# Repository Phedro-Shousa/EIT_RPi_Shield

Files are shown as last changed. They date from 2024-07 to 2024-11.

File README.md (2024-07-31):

# EIT_RPi_Shield: Electrical Impedance Tomography (EIT) Shield for Structural Health Monitoring (SHM)

## Overview

This project is an Electrical Impedance Tomography (EIT) shield system designed for Structural Health Monitoring (SHM). This shield is an educational device that allows you to "plug-and-play" and actively collect data using a Raspberry Pi.

## Hardware Setup

The hardware setup consists of:
- 16 electrodes
- 1 High-Speed ADC
- Amplitude and Phase Detector
- 2 Multiplexers (Mux)
- Wave Generator

The shield is powered by the Raspberry Pi's 5V supply, with added protection. In addition to these sensors, this shield has extra free pinouts from the ADC analog inputs and the Raspberry Pi, allowing for the testing of other sensors and components.

## Project Status

This is the first stage of a work in progress, with the PCB design currently concluded. Future improvements and code will be developed in the future. This project belongs to the Würzburg University Luft- und Raumfahrtinformatik department.

**Note:** This shield is not recommended for medical use or for use on people, as it does not comply with current health regulations. It is intended only for SHM use on objects.

## Electrical Specifications

| Component | Specification |
|---|---|
| Power Supply | 5V (from Raspberry Pi) |
| Electrodes | - 16 Electrodes |
| | - 5 free ADC channels |
| ADC | - Input range ±5V or ±10V |
| | - 16-bit 20KSPS |
| Phase-Gain Detector | - Up to signals of 2.7GHz |
| | - Gain scale of 30mV/dB |
| | - Phase scale of 10mV/degree |
| Wave Generator | - Output signal up to 12MHz |
| | - Serial CLK up to 40MHz |
| | - Output signal voltage: Max 4.9V (load of 100Ω) or 4.5V (1kΩ) |
| | - Output signal voltage: Min 0.4V |
| MUX | - 4Ω on resistance |
| | - Rail-to-rail |
| | - Serial CLK up to 30MHz |

## Pictures
### Board

### Schematic
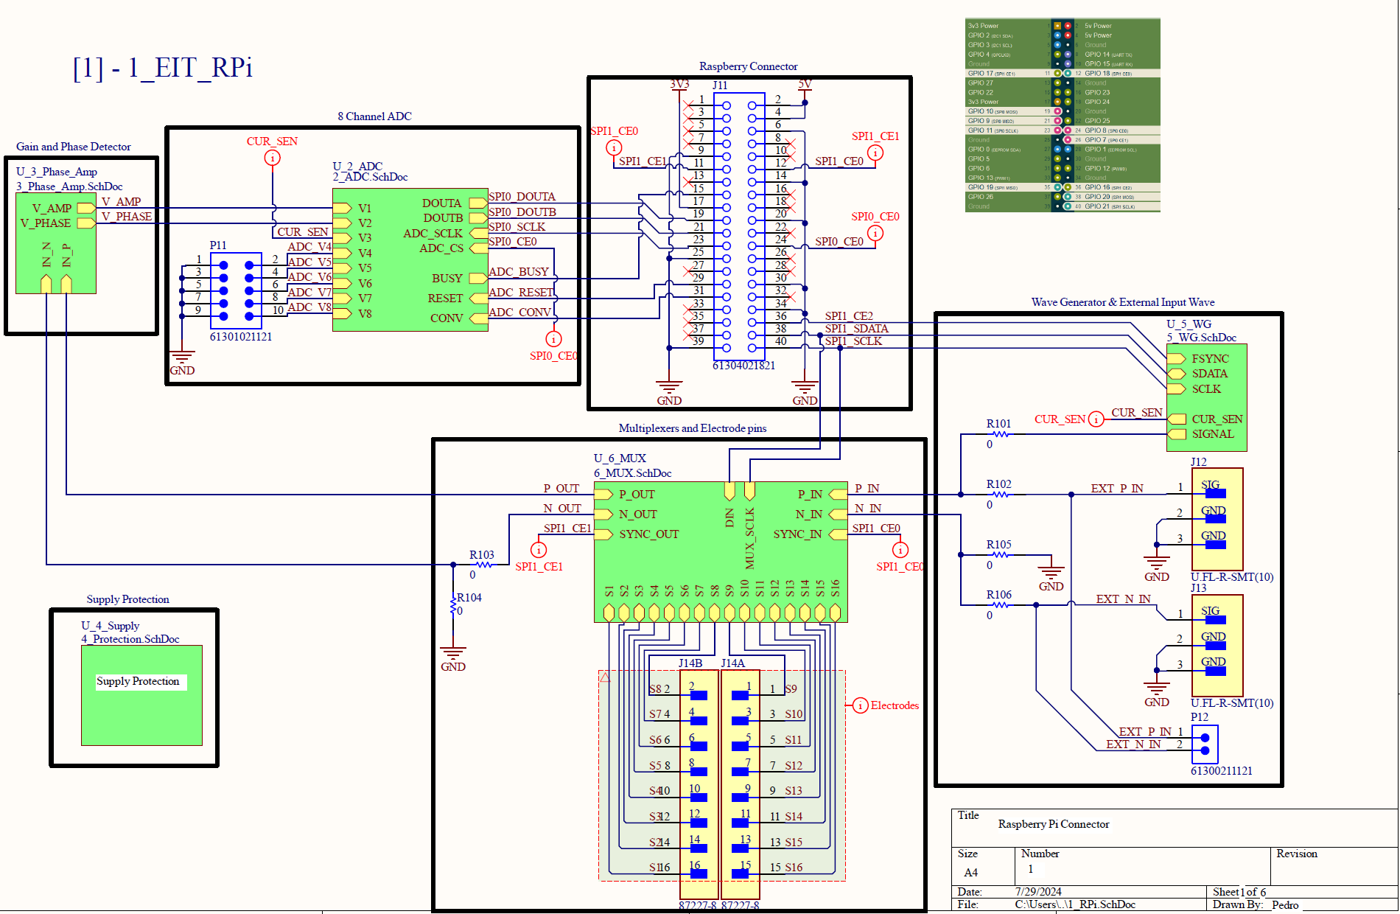
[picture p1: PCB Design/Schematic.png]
Schematic Picture


### PCB Layout
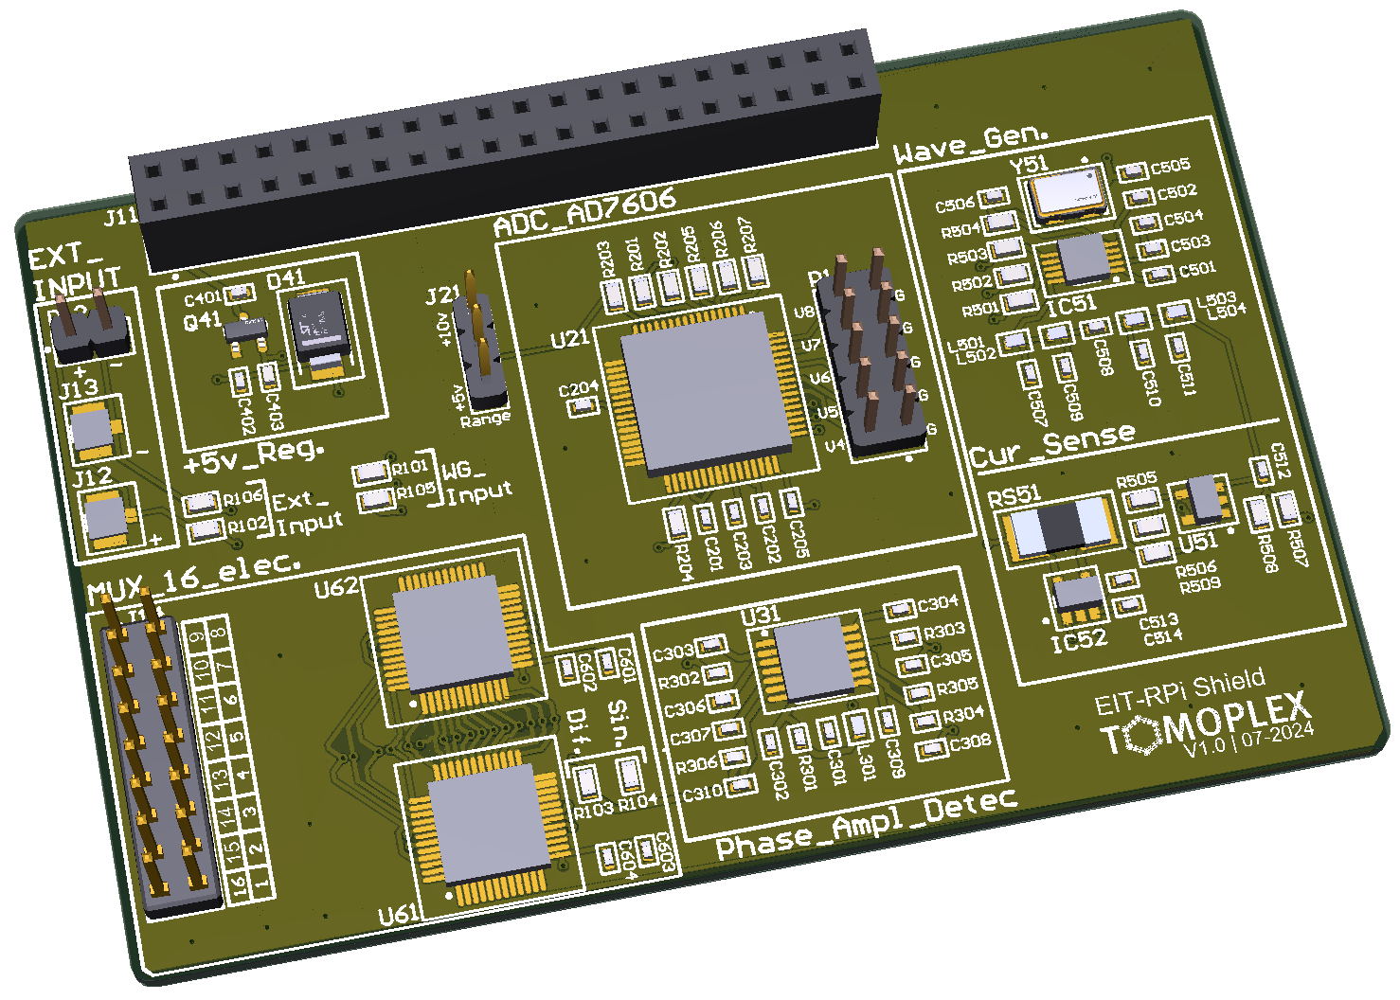
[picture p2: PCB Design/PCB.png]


---

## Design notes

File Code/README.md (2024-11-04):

# Code for EIT RPi Shield

This folder contains all the source code and scripts necessary to run the Electrical Impedance Tomography (EIT) Raspberry Pi Shield, which includes components like ADC interfacing, current sensing, multiplexing, and waveform generation.

### 1. `EIT_Test/`
This folder contains scripts for testing the entire EIT system.
- **AD7606.py**: Functions for interacting with the AD7606 ADC.
- **AD9833.py**: Code to control the AD9833 waveform generator.
- **ADG725.py**: Script for handling the ADG725 multiplexer.
- **main.py**: Main script to run EIT testing.
- **send_data.py**: Sends test data from the Raspberry Pi.
- **spi6-extended.dtbo**: SPI configuration for the test setup.

### 2. `ADC_AD7606/`
- **main.py**: Main script to run and initialize the ADC.
- **rpi_ad7606.py**: Supporting functions to handle the SPI communication between the Raspberry Pi and AD7606.

### 3. `Current_Sense/`
- **main.py**: Script to run current sensing using the MAX4376 current sense amplifier.
- **rpi_ad7606.py**: Functions for ADC (AD7606) interfacing.
- **spi6-extended.dtbo**: Device Tree Blob for configuring SPI6 interface.
- **spi6-extended.txt**: Configuration details for the SPI6.
- **Data_Results/**: Folder containing measurement results at different frequencies (1kHz to 1MHz).

### 4. `Mux/`
- **ADG725.py**: Script for initializing and using the multiplexer.
- **test.py**: Test script to verify multiplexer functionality.

### 5. `WavGen_AD9833/`
- **main.py**: Script for generating waveforms.
- **rpi_ad7606.py**: Helper functions to read waveform data using the AD7606.
- **spi6-extended.dtbo**: SPI6 interface configuration for waveform generation.

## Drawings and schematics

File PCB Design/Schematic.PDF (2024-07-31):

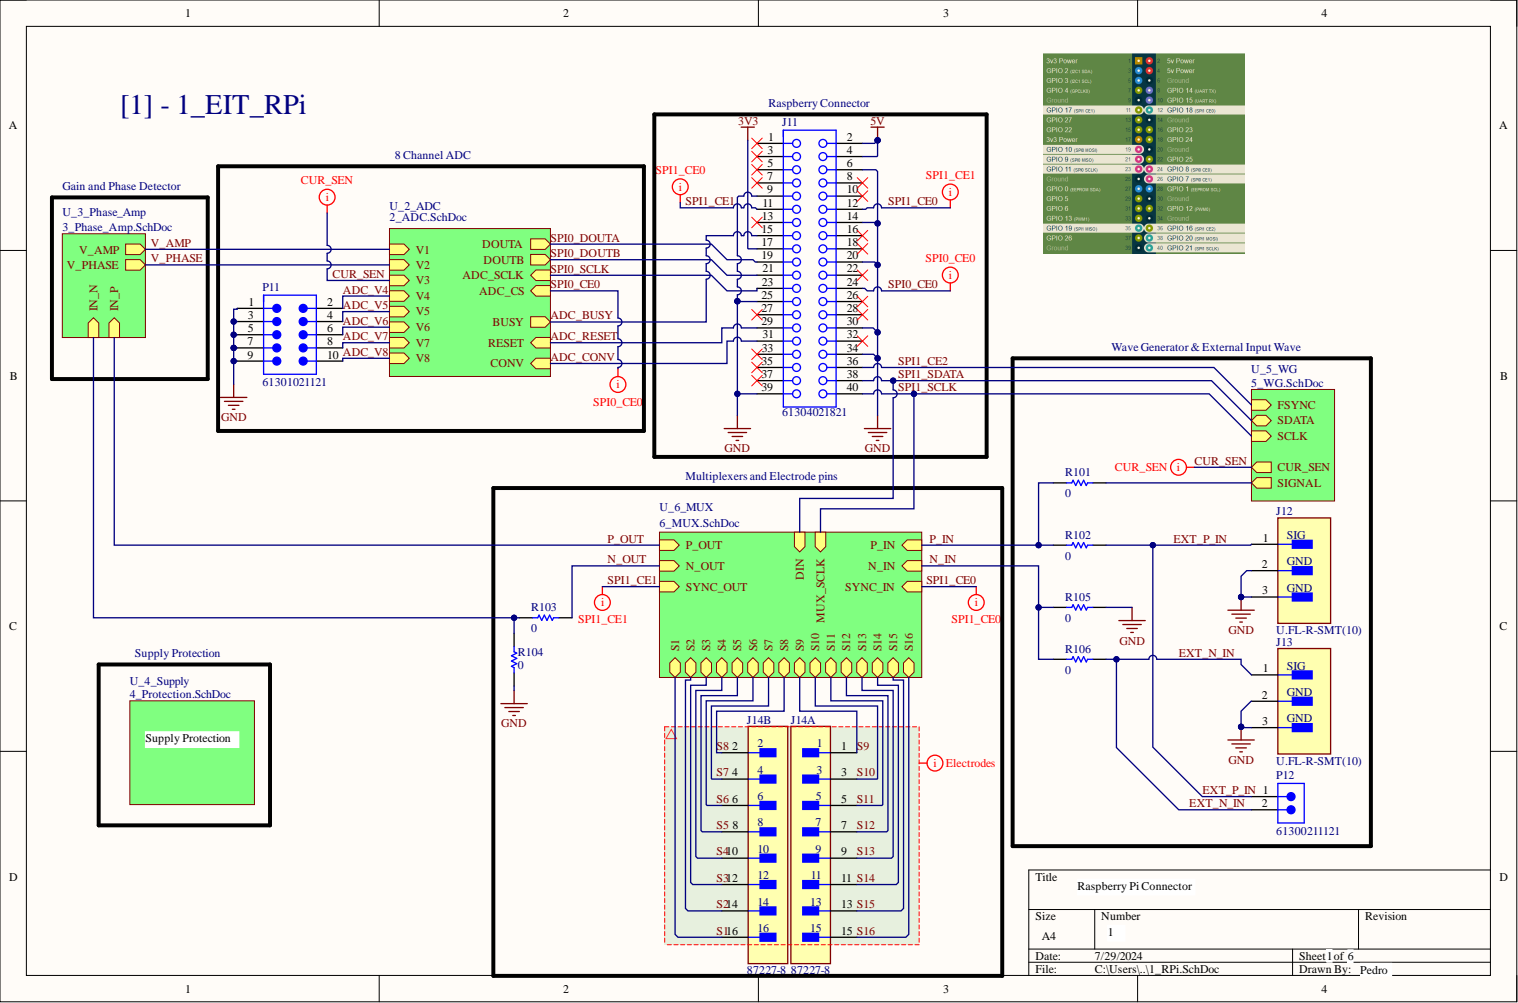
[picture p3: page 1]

Gain and Phase Detector

CUR_SEN | i

V_PHASE

ADC_V5 | | ADC_BUSY

ADC_V7 | ADC_RESET

V7 RESET V8 CONV

Wave Generator & External Input Wave

SPI0_CE0 | i | 37 | 38

Multiplexers and Electrode pins

P_OUT | U_6_MUX 6_MUX.SchDoc | P_IN N_IN

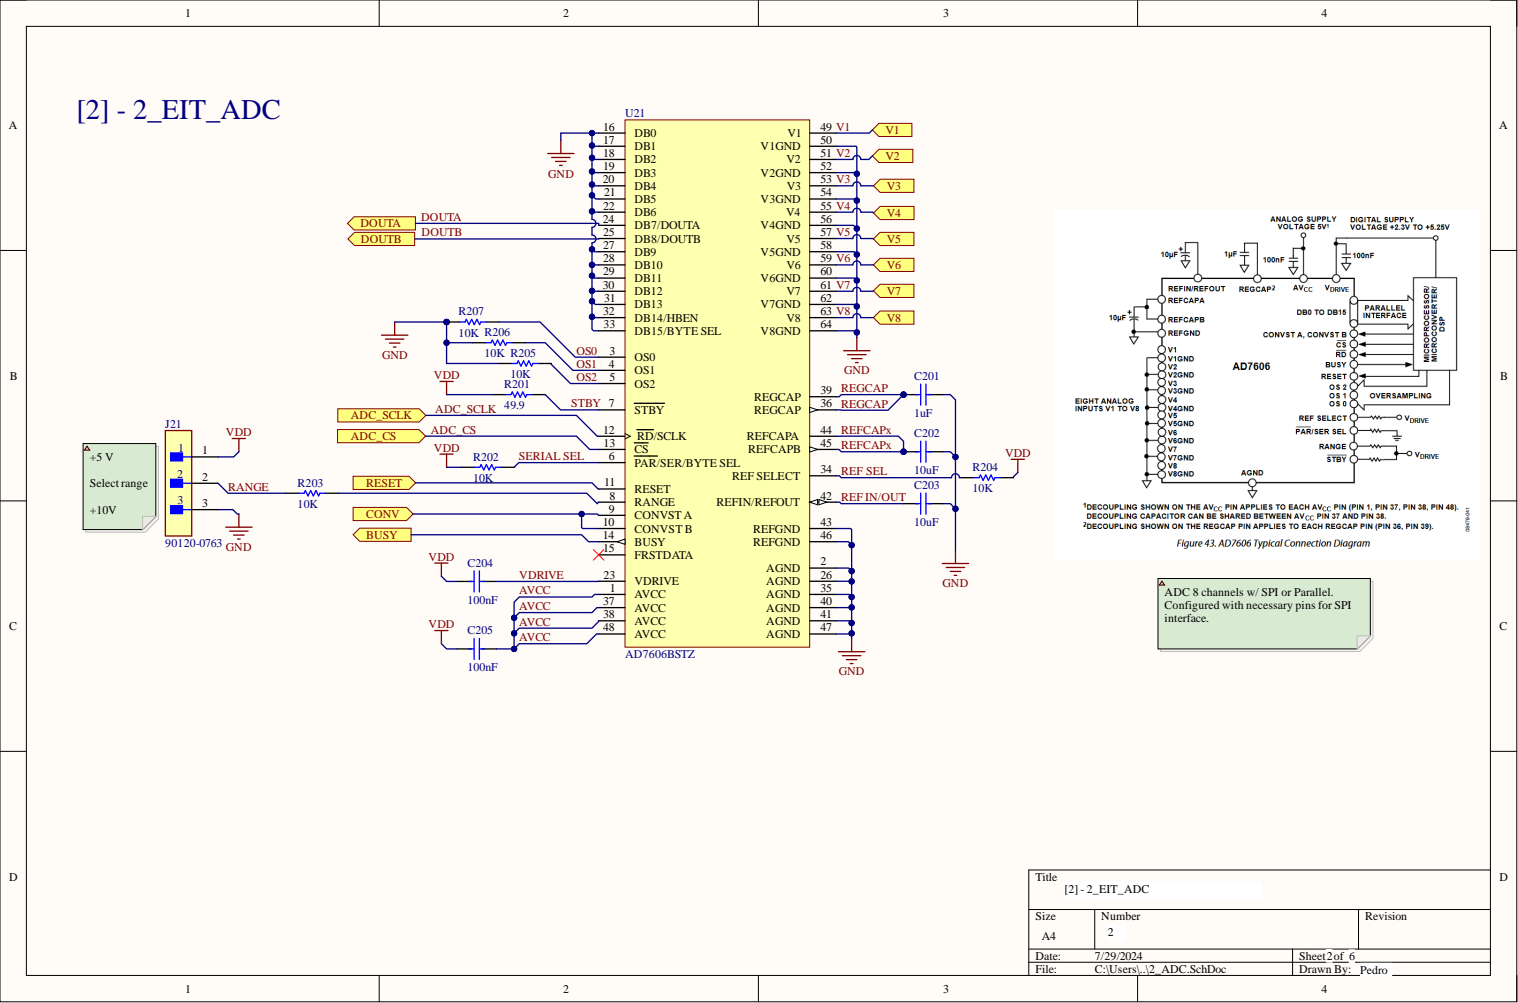
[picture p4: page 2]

RD/SCLK 12
PAR/SER/BYTE SEL 6

ADC 8 channels w/ SPI or Parallel.
Configured with necessary pins for SPI
interface.

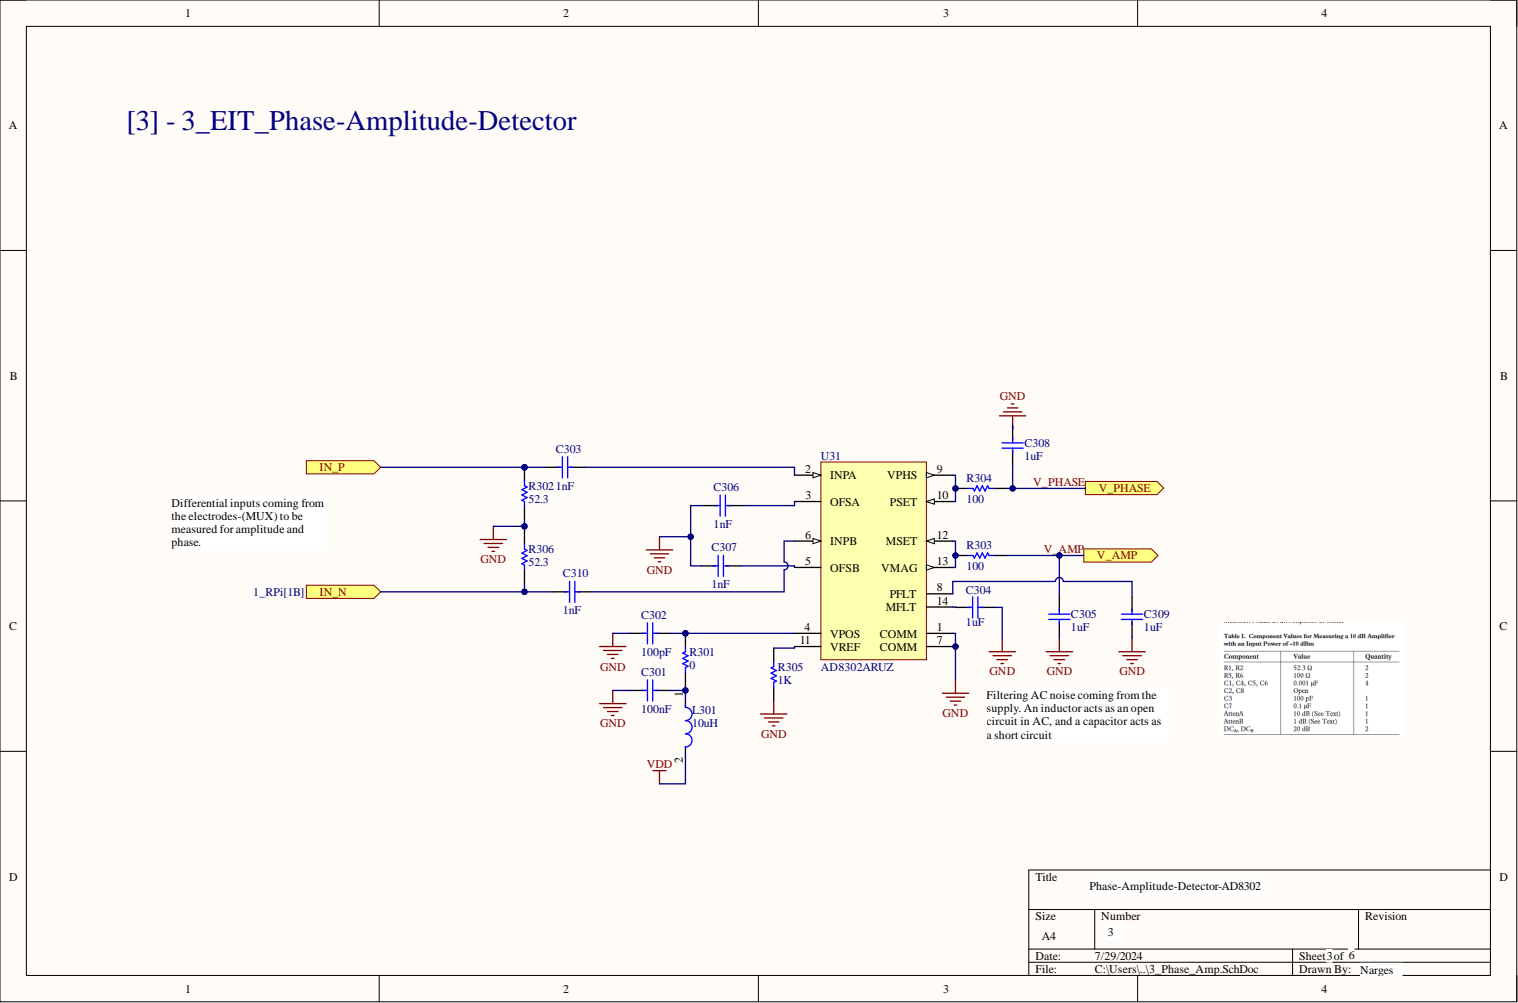
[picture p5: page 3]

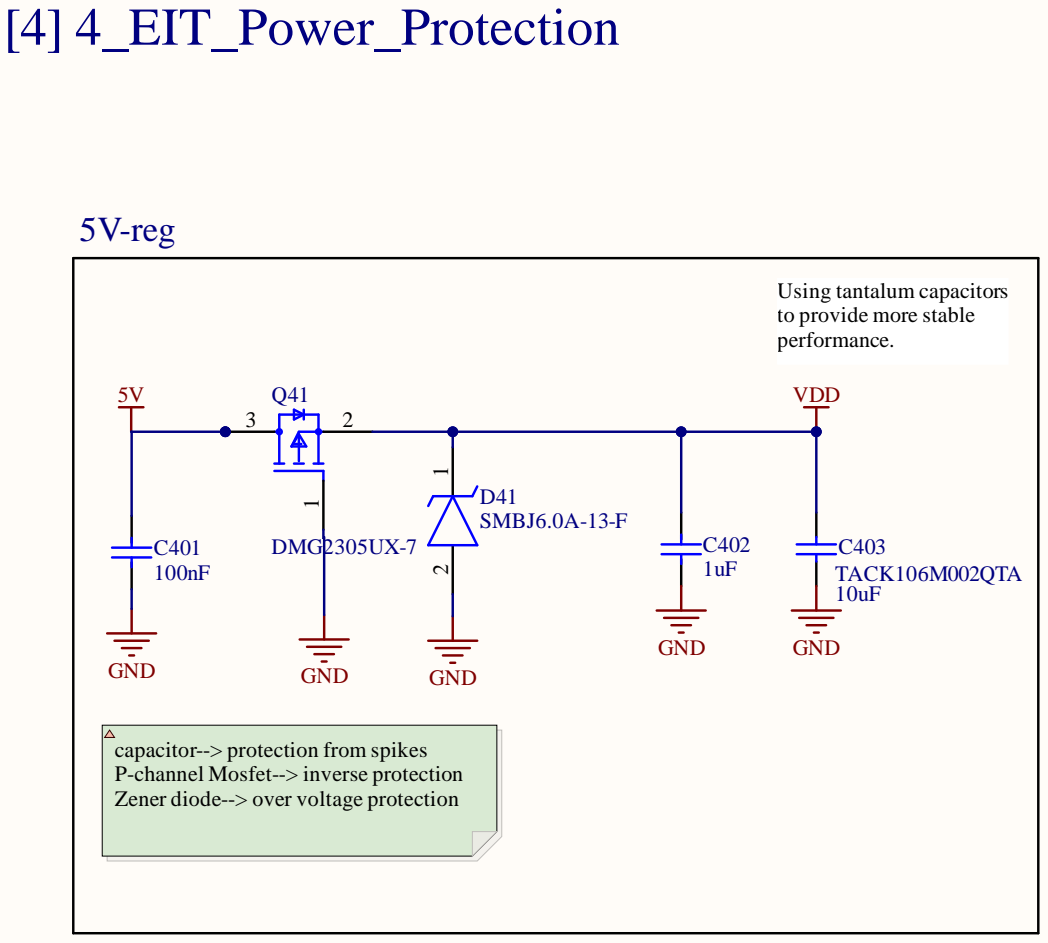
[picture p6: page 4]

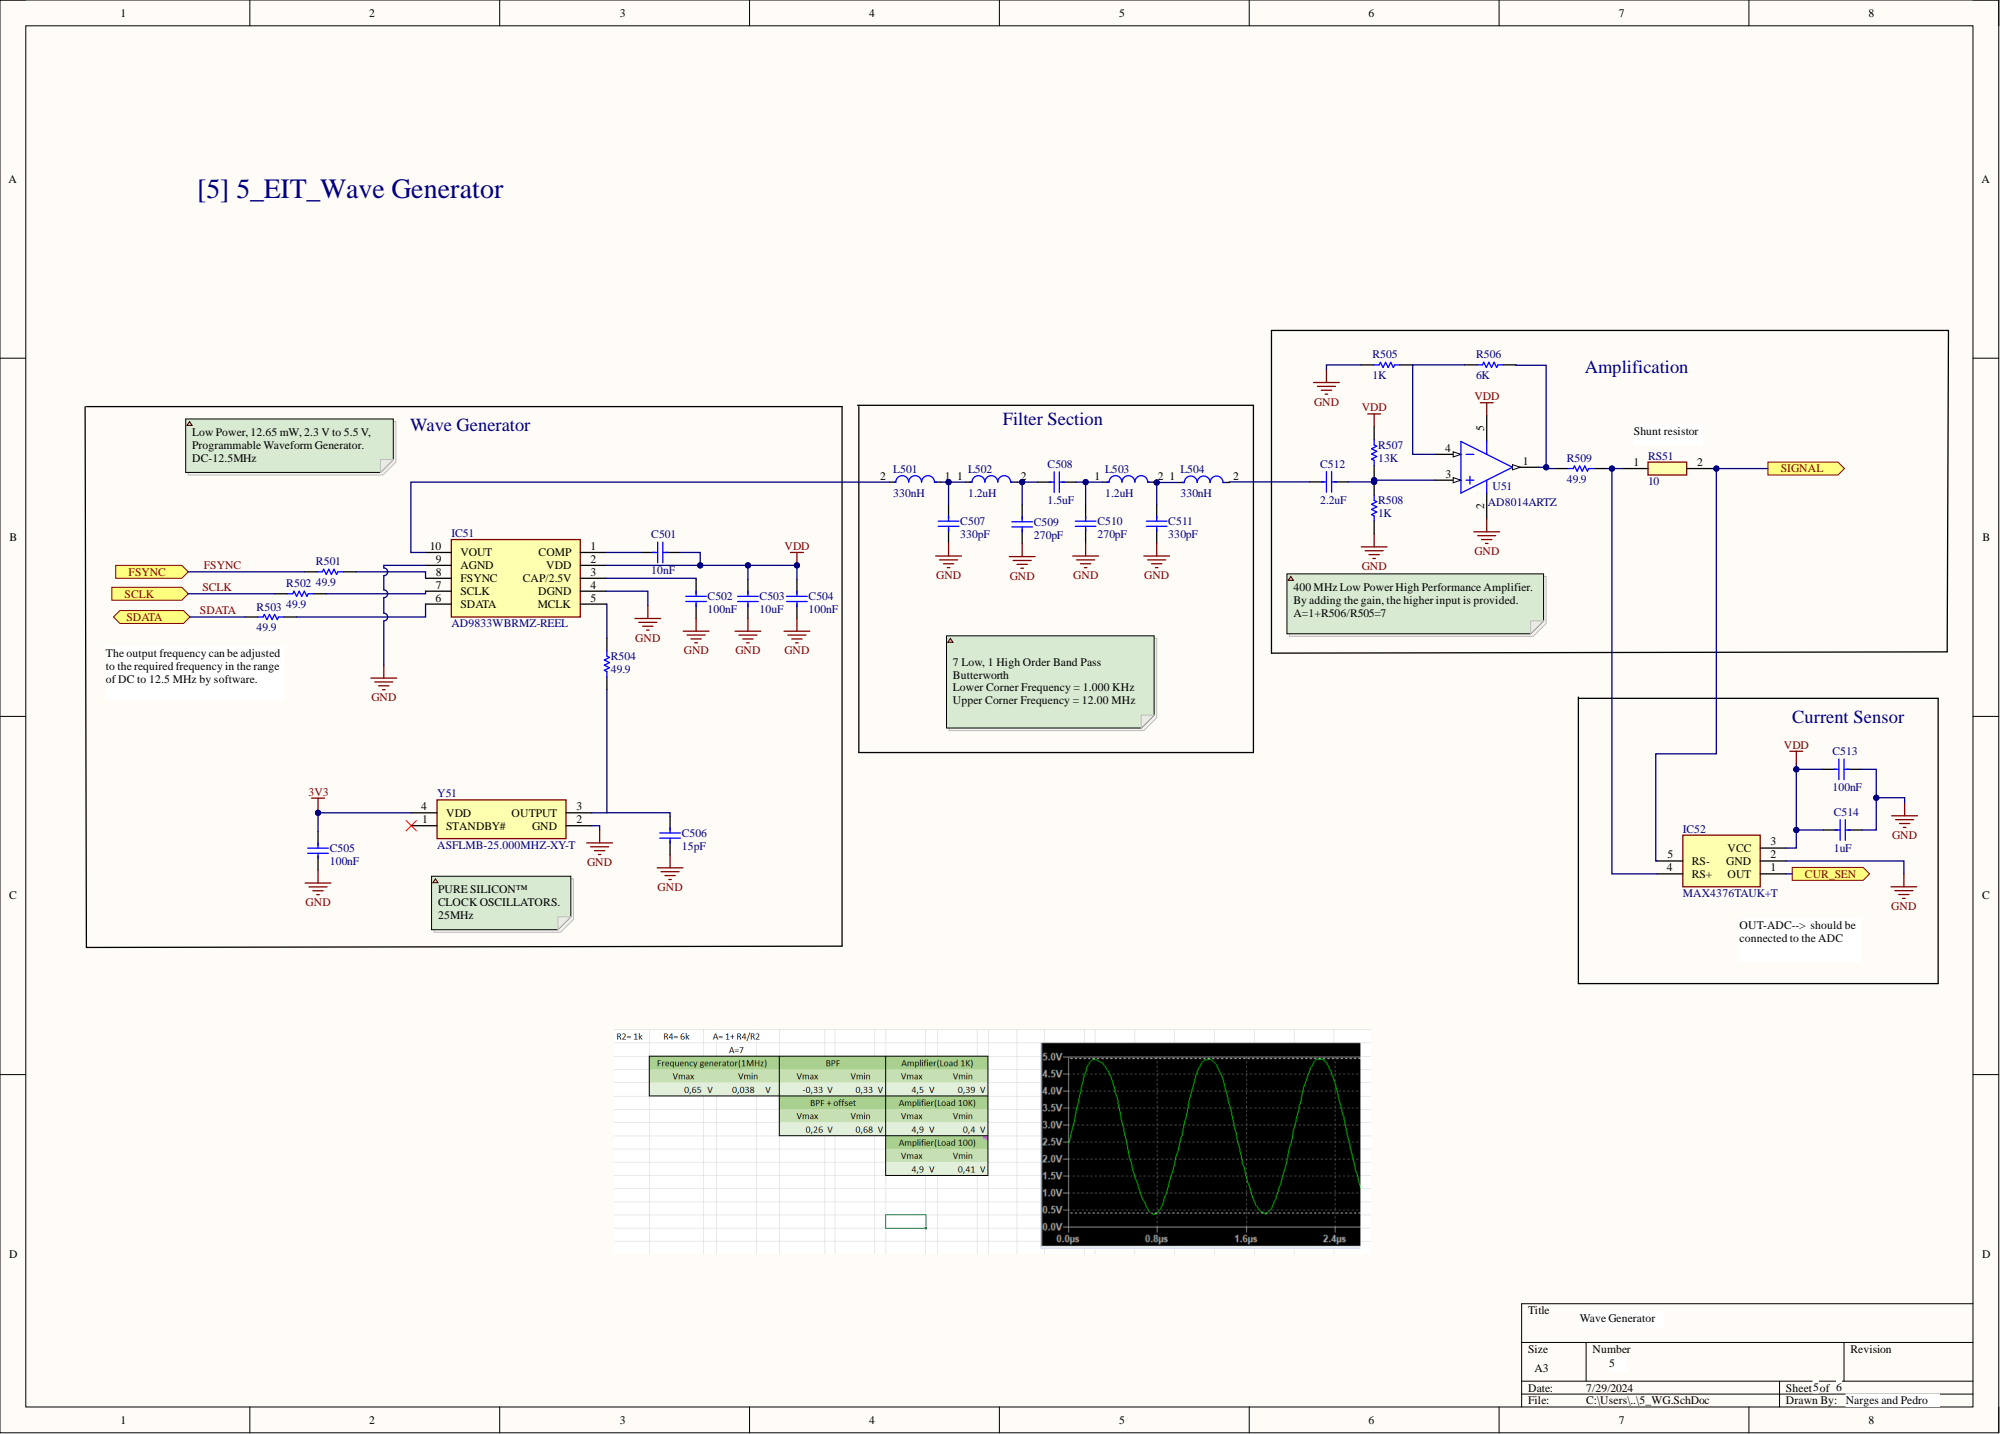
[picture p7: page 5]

Low Power, 12.65 mW, 2.3 V to 5.5 V,
Programmable Waveform Generator.
DC-12.5MHz

400 MHz Low Power High Performance Amplifier.
By adding the gain, the higher input is provided.

The output frequency can be adjusted
to the required frequency in the range
of DC to 12.5 MHz by software.

7 Low, 1 High Order Band Pass
Butterworth
Lower Corner Frequency = 1.000 KHz
Upper Corner Frequency = 12.00 MHz

OUT-ADC--> should be
connected to the ADC

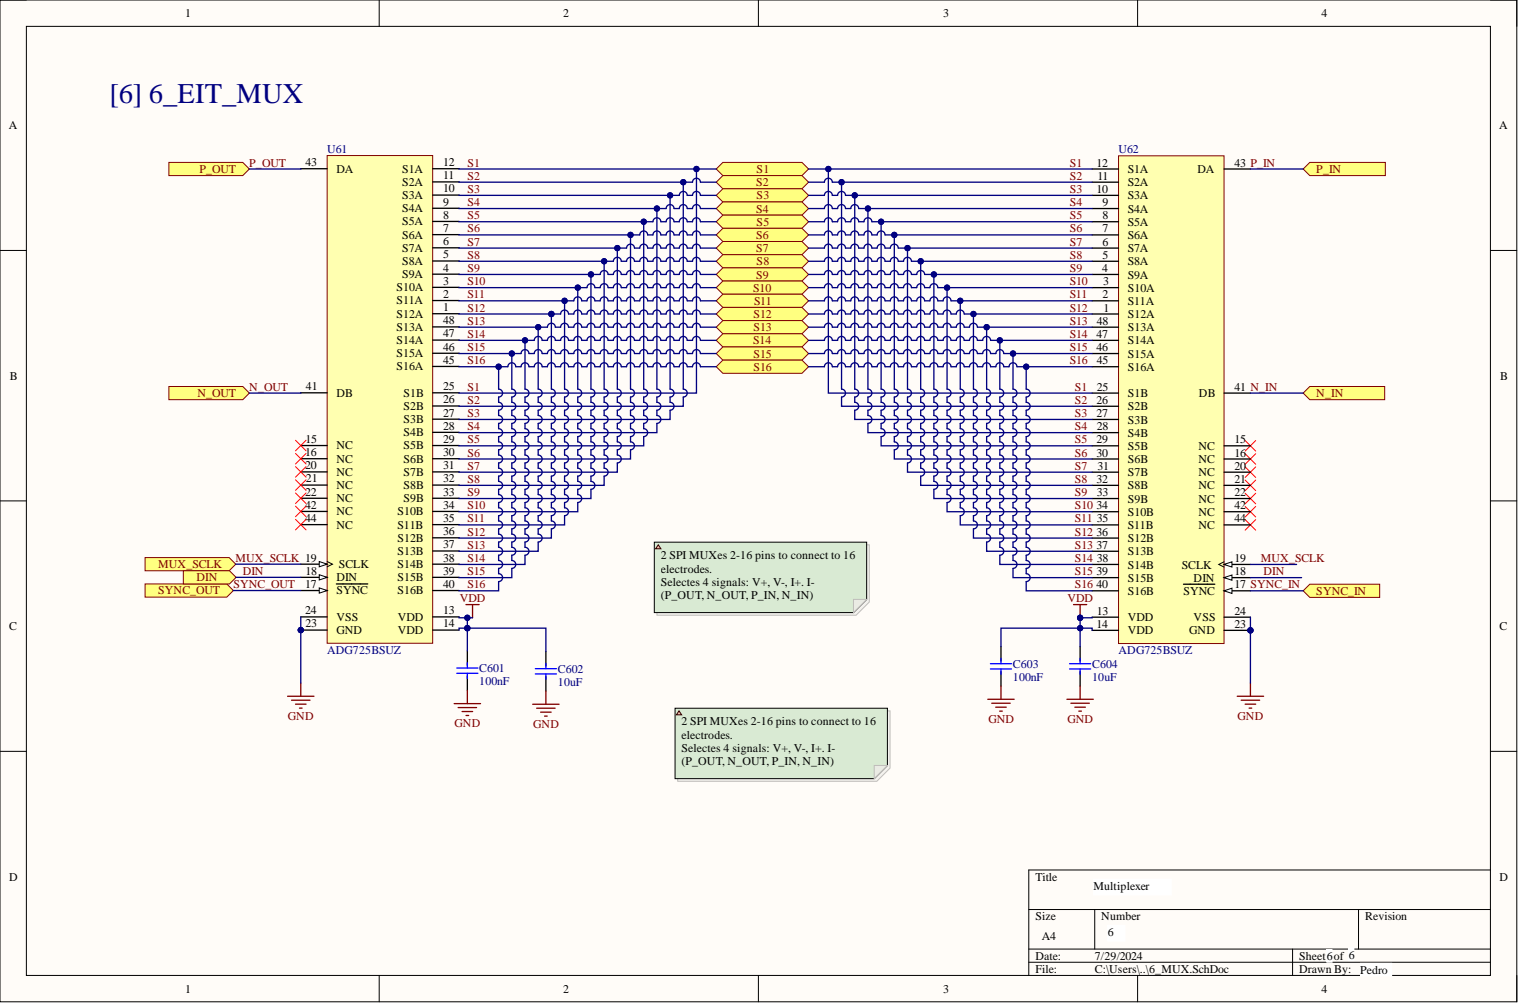
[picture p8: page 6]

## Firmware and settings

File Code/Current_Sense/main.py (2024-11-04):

import spidev
import RPi.GPIO as GPIO
import keyboard  # To detect keypresses
import rpi_ad7606 as adc
import time
import subprocess

def write_data_to_file(data, filename="/home/pedro/Desktop/log.txt"):
    # Write the data to a temporary file on Raspberry Pi
    with open(filename, 'w') as f:
        f.write(data)


def transfer_file_to_laptop(filename):
    # SSH details
    user = "Pedro Sousa"  # Replace with your laptop's username
    ip = "132.187.210.53"  # Replace with your laptop's IP address

    # Correct the file path on Windows laptop with double backslashes and quotes
    destination_path = r"C:\\Users\\Pedro Sousa\\Desktop\\TOMOPLEX\\Redesign\\Rasp_Code\\log.txt"

    # Use scp to transfer the file to the laptop
    command = f"scp {filename} \"{user}@{ip}:{destination_path}\""
    
    # Execute the scp command to transfer the file
    subprocess.run(command, shell=True)

def main():
    freq = 1000
    ClockFreq = 25000000
    
    print("Wav_Gem Test \n")
    GPIO.setmode(GPIO.BCM)
    spi = spidev.SpiDev(6, 2)
    spi.max_speed_hz = 10000000 
    spi.mode = 0b10
            
    adc_pins = {'standby':None, 'convsta':6, 'reset':5, 'busy':22, '1stData':None}
    adc1 = adc.AD7606_SPI(5, 'simultaneous', adc_pins)
    print("ADC Object Created \n")
    adc1.ADCreset()
    print("ADC Reset \n")
    
    # Send a reset
    spi.xfer([0x21, 0x00]) 
    print("Reset 0x2100 \n")
    
    # Calculate frequency word to send
    word = hex(int(round((freq * 2**28) / ClockFreq)))
    
    # Split frequency word onto its separate bytes
    MSB = (int(word, 16) & 0xFFFC000) >> 14
    LSB = int(word, 16) & 0x3FFF
    
    # Set control bits DB15 = 0 and DB14 = 1; for frequency register 0
    MSB |= 0x4000
    LSB |= 0x4000
    
    # Send LSB
    high, low = divmod(LSB, 0x100)
    spi.xfer([high, low])  # LSB
    
    # Send MSB
    high, low = divmod(MSB, 0x100)
    spi.xfer([high, low])  # MSB
    
    # Print the hexadecimal representation of MSB and LSB
    print(f"Frequency register MSB: {hex(MSB)}, LSB: {hex(LSB)}")
    
    # Phase register 0°
    spi.xfer([0xC0, 0x00])  # MSB
    print("Phase register 0xC000 \n")
    
    # Sine wave
    spi.xfer([0x00, 0x00])  # Sine
    print("Sine 0x0000 \n")
    
    channel = 3
    # Format the ADC readings as a string
    data = ""
    samples = 1024
    
    while samples > 0:
        r = adc1.ADCread(channel)
        reading = "{v}".format(v=r)
        data += reading + "\n"
        samples -= 1
    
    print(data)
    # Write the formatted data to a file on the Raspberry Pi
    write_data_to_file(data)        
    # Transfer the file to the Windows laptop
    transfer_file_to_laptop("/home/pedro/Desktop/log.txt")
    
    adc1.close()  # Close the SPI and cleanup GPIO

    
if __name__ == '__main__':
    main()

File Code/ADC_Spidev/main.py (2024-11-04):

import time
import rpi_ad7606 as adc

def main():
    adc_pins = {'standby':None, 'convsta':6, 'reset':5, 'busy':22, '1stData':None}
    adc1 = adc.AD7606_SPI(5, 'simultaneous', adc_pins)
    print("ADC Object Created \n")

    adc1.ADCreset()
    print("ADC Reset \n")
    
    r = adc1.ADCread()
    _ch = 1
    for _r in r:
        print(f"Channel {_ch}: {_r} volts. \n")
        _ch += 1
        time.sleep(1)

    adc1.ADCreset()
    print("ADC Reset \n")

    adc1.close()  # Close the SPI and cleanup GPIO

if __name__ == '__main__':
    main()

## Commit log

2024-07-25 add _PCB Design_ folder
    [1_RPi.SchDoc, 2_ADC.SchDoc, 2_RPi.PcbDoc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]
2024-07-25 title size update
    [2_ADC.SchDoc]
2024-07-25 Generating Documentation
    [2_RPi.PcbDoc, PCB_Project.PrjPcb]
2024-07-25 update output doc
    [2_RPi.PcbDoc]
2024-07-25 fix folder name
    [1_RPi.SchDoc, 2_ADC.SchDoc, 2_RPi.PcbDoc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]
2024-07-29 updating info text
    [3_Phase_Amp.SchDoc, 4_Supply.SchDoc, 6_MUX.SchDoc]
2024-07-29 Adding text and info, and formatting for better understanding
    [1_RPi.SchDoc, 2_ADC.SchDoc, 2_RPi.PcbDoc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]
2024-07-31 schematic pdf update
2024-08-01 Fixing Layer to a Sig/pwr-GND-GND-Sig/pwr Stack
    [2_RPi.PcbDoc]
2024-08-05 updated rules
    [2_RPi.PcbDoc]
2024-08-06 Updated Capacitors footprint
    [2_ADC.SchDoc, 5_WG.SchDoc, 6_MUX.SchDoc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]
